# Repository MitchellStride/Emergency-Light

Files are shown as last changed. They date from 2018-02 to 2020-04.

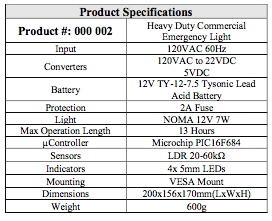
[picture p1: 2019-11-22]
pics/prod-spec.png

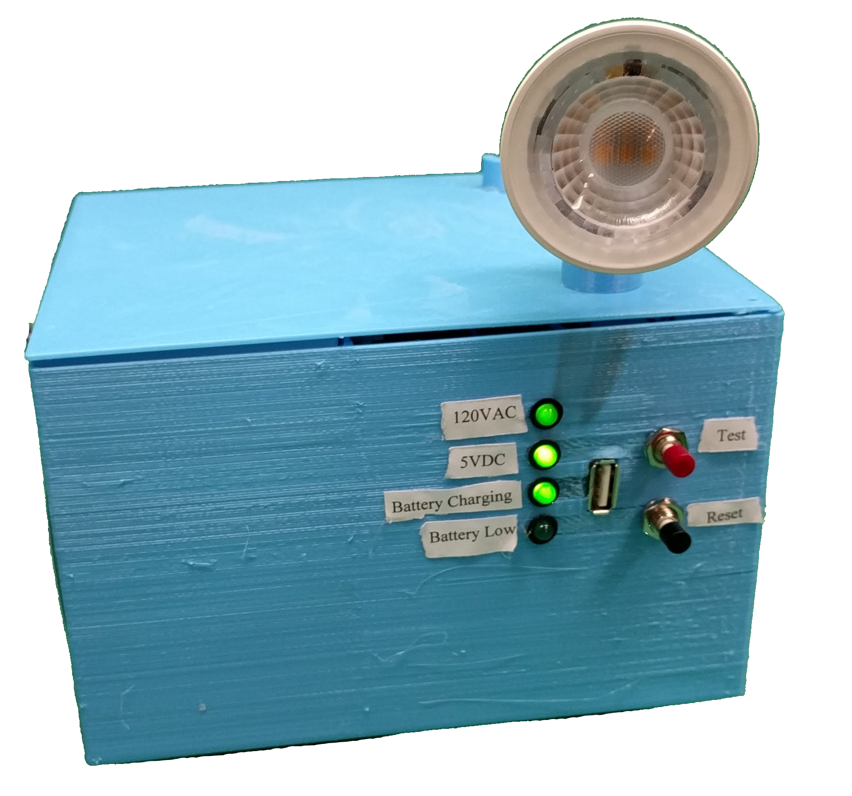
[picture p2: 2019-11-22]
pics/Emergency-Front.png

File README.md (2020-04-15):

# MayoStride Innovations

Emergency Light Lab by Mitchell Stride, and Jordan Mayo.

## Emergency Light Unit







## Product Specifications









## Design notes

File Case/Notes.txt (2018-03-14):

Case Notes
Inside
Battery,
Board mount
Transformer
Room for cables

Outside
Light Mount on top
Hole for Light mount wires
Hole for power plug cord
4 Leds
2 Switches buttons
usb charging slot
LDR hole

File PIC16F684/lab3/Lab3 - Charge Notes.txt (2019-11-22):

// From Lab3 Manuel
program LAB3_PWM_CHRG
dim dc1 as byte
main:
TRISA = S01
cmcon0=0 'comparatorsoff
ANSEL=$01
ADCON0=$80 'right justified
ADCON1=$70 'set clock frequency
TRISC = 0
PORTC=$FF 'initial value
PWM1_Init(1000) ' initializes PWM module, freq = 1kHz.
PWM1_Start ' starts PWM
While true
dc1= word(ADC_read(0) >> 2) 'read adc and kick two LSBs out Delay_ms(100) 'change duty every 100ms PWM1_Set_Duty(dc1) ' changes duty ratio
wend
end.

//Our Code
//tomoarr add comments, spruce up, see if works

program LAB3_PWM_CHRG
dim data1 as float
dim vadc as float
dim dc1 as float

main:
TRISA = $01
cmcon0=0 'comparatorsoff
ANSEL=$01
ADCON0=$80 'right justified
ADCON1=$70 'set clock frequency
TRISC = 0
PORTC=$FF 'initial value
PWM1_Init(1000) ' initializes PWM module, freq = 1kHz.
PWM1_Start ' starts PWM

While true
data1 = adc_read(0)
vadc = (5*data1)/1023
dc1 = 951.1-190.3*vadc
PWM1_Set_Duty(dc1)
Delay_ms(100)
wend
end

//Done
program LAB3_PWM_CHRG

dim vadc as float
dim dc1 as float
dim data1 as word

main:
TRISA = $01
cmcon0=0            'comparators off
ANSEL=$01
ADCON0=$80          'right justified
ADCON1=$70          'set clock frequency
TRISC = 0
PORTC=$FF           'initial value
PWM1_Init(1000)     'initializes PWM module, freq = 1kHz.
PWM1_Start          'starts PWM

While true
data1 = adc_read(0)         'Reading adc
vadc = (5*data1)/1023       'Converting
dc1 = 951.1-190.3*vadc      'Calculated conversion
PWM1_Set_Duty(dc1)          'Setting PWM
Delay_ms(100)
wend

end.

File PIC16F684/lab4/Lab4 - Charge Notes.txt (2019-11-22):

program Lab4_EmergencyLight

'Pinout of Circuit
'AI0 - Data for Vbattery (Pin13)
'AI1 - Rectified voltage read (Pin 12)
'AI2 - LDR read (Pin 11)

'RC0 - Test Button (Pin 10)
'RC1 - Charging LED (Pin 9)
'RC2 - Low Battery LED (Pin 10)
'RC3 - Light Relay (Pin 7)
'RC5 - PWM Charging (Pin5)

'Init Variables
dim pwm_data as float
dim pwm_vadc as float
dim pwm_dutyCycle as float
dim rectified_data as float
dim rectified_vadc as float
dim light_data as float
dim light_vadc as float

main:

'Init Ports (0-Output, 1-Input)
TRISA = %00000111   'RA7-RA0
TRISC = %00000001   'RC7-RC0
PORTA = %00000000   'RA7-RA0
PORTC = %00000000   'RC7-RC0

cmcon0 = 0    'Turn Comparators Off

'Init ADC
ANSEL = $0F
ADCON0 = $80
ADCON1 = $70

'PWM Init (lab3)
PWM1_Init(1000)
PWM1_Start

 PORTC.3 = 0' Turn Light Off

while true
    'Read battery level to set PWM
      pwm_data = adc_read(0)
      pwm_vadc = (5*pwm_data)/1023
      pwm_dutyCycle = 951.1-(190.3*pwm_vadc)
    'Read grid rectified voltage
      rectified_data = adc_read(1)
      rectified_vadc = (5*rectified_data)/1023
    'Read light value from LDR
      light_data = adc_read(2)
      light_vadc = (5*light_data)/1023

      if PORTC.0 = 1 then   'Read Switch, if not pushed
         if rectified_vadc > 3 then   'Rectified voltage available
            PWM1_Set_Duty(pwm_dutyCycle)    'Set duty cycle
            PORTC.2 = 0                     'Low Battery LED OFF
            PORTC.1 = 1                     'Battery Charging LED ON
            PORTC.3 = 0                     'Light OFF

         else                          'Rectified voltage not available
            if pwm_vadc > 3.83 then         'Battery is operational
               if light_vadc > 2.5 then     'Dark Room
                  PORTC.1 = 0               'Battery Charging LED OFF
                  PORTC.3 = 1               'Light ON
               else                         'Light Room
                  PORTC.1 = 0               'Battery Charging LED OFF
                  PORTC.3 = 0               'Light OFF
               end if
            else                            'Battery is NOT operational
               PORTC.2 = 1                  'Low Battery LED ON
               PORTC.1 = 0                  'Battery Charging LED ON
               PORTC.3 = 0                  'Light OFF
            end if
         end if

      else                            'If Switch is pushed
          PORTC.3 = 0                 'Light ON
          PORTC.1 = 1                 'Battery Charging LED OFF
      end if

      delay_ms(1000)                  'Delay a second
  wend
end.

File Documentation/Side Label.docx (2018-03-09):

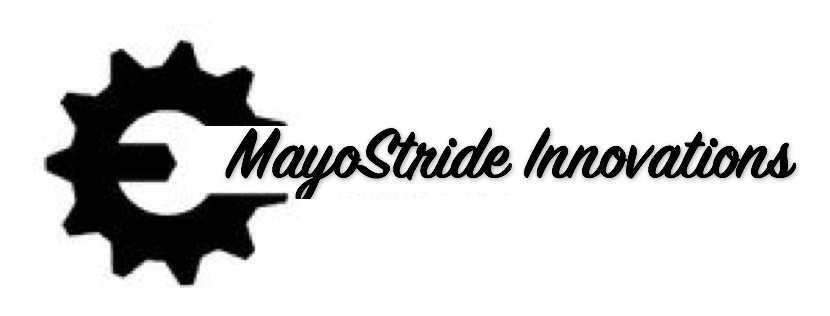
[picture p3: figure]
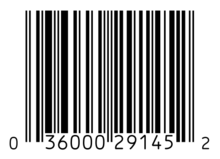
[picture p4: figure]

MayoStride Innovations

S.J Carew – EN1040

230 Elizabeth Ave, St. Johns

NL A1C 5S7

Canada

Product Specifications
Product #: 000 002 | Heavy Duty Commercial Emergency Light
Input | 120VAC 60Hz
Converters | 120VAC to 22VDC 5VDC
Battery | 12V TY-12-7.5 Tysonic Lead Acid Battery
Protection | 2A Fuse
Light | NOMA 12V 7W
Max Operation Length | 13 Hours
µController | Microchip PIC16F684
Sensors | LDR 20-60kΩ
Indicators | 4x 5mm LEDs
Mounting | VESA Mount
Dimensions | 200x156x170mm(LxWxH)
Weight | 600g

Reset

Test

120VAC

5VDC

Battery Low

Battery Charging

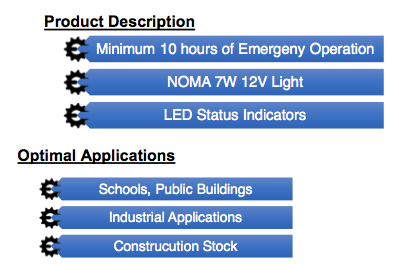
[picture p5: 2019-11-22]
pics/brochure-snip.png

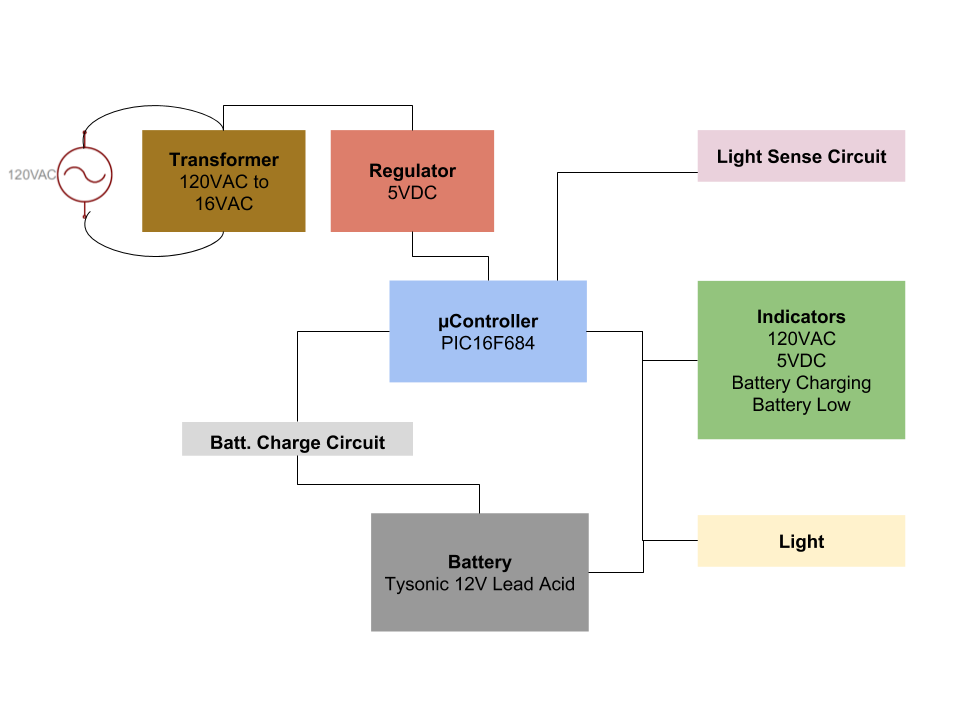
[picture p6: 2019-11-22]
pics/Block-Diagram.png

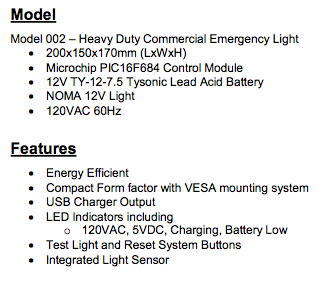
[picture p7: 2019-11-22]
pics/txtpic.png

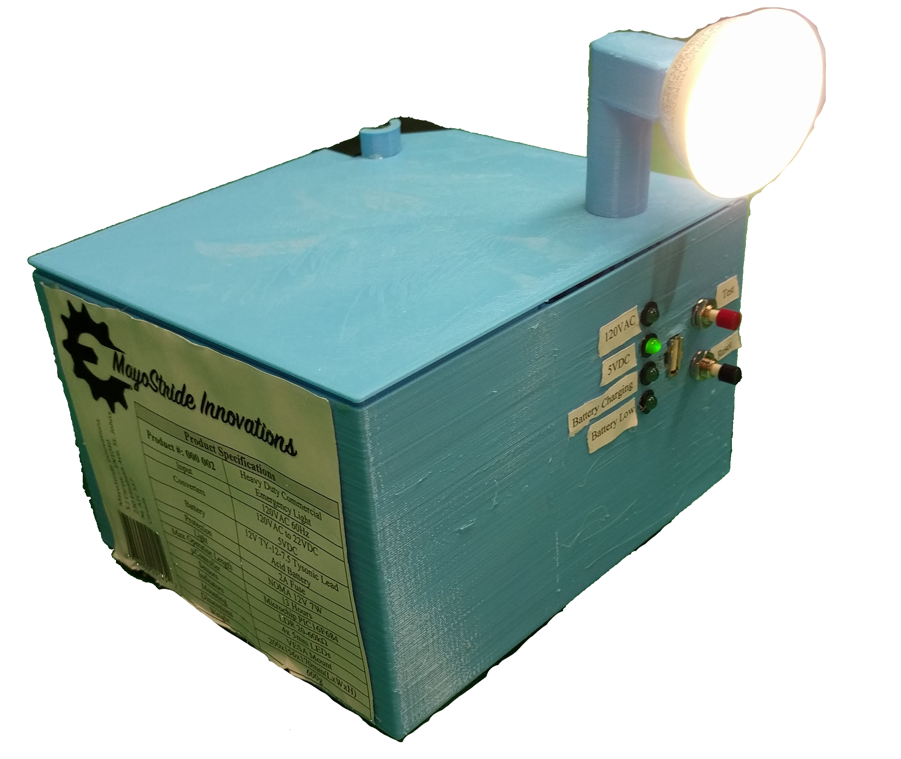
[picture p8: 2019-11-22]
pics/TriMetric-View Emergency-Light.png

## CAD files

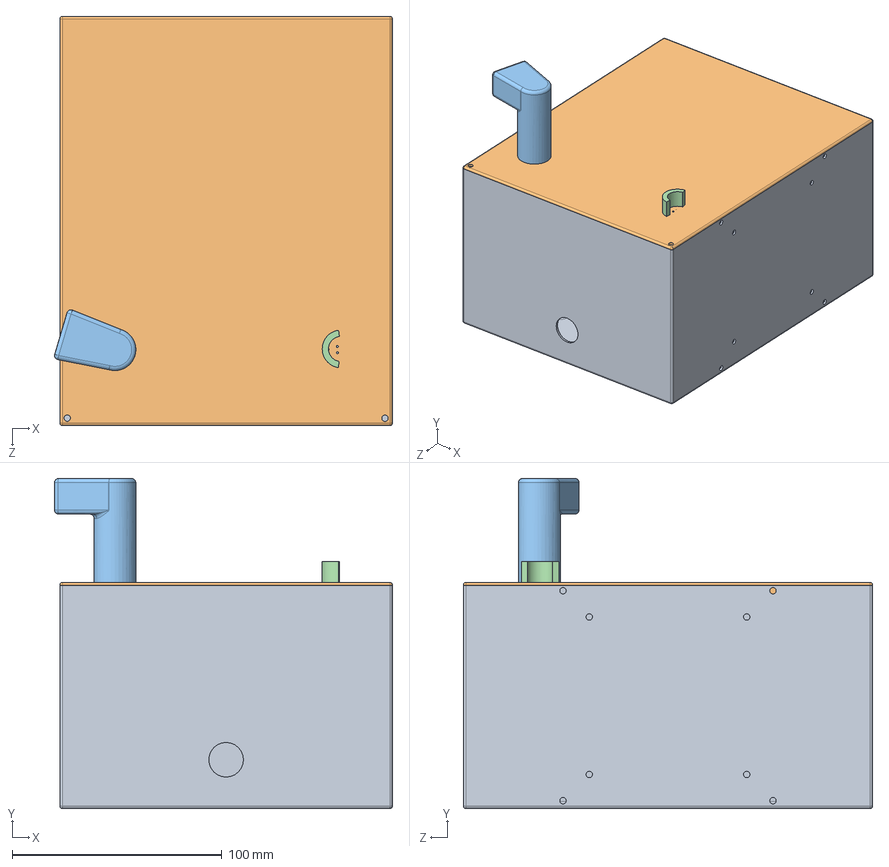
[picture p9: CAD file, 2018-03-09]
Case/Assembly.SLDASM
161.0 x 157.2 x 195.0 mm
CaseBase
CaseCover
Light Mount
Shroud

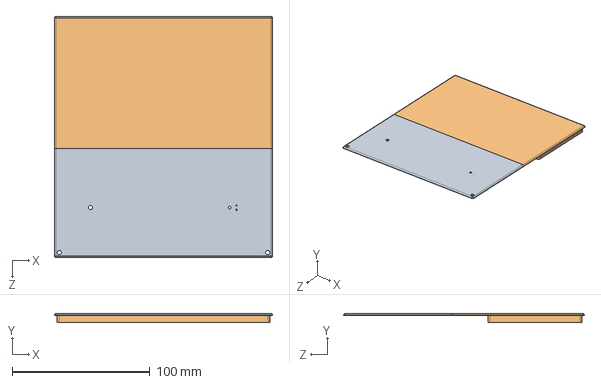
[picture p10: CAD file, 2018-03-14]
Case/Case Cover Fix/Case Top Fix Assem.SLDASM
158.5 x 6.50 x 175.0 mm
CaseCover1
CaseCover2

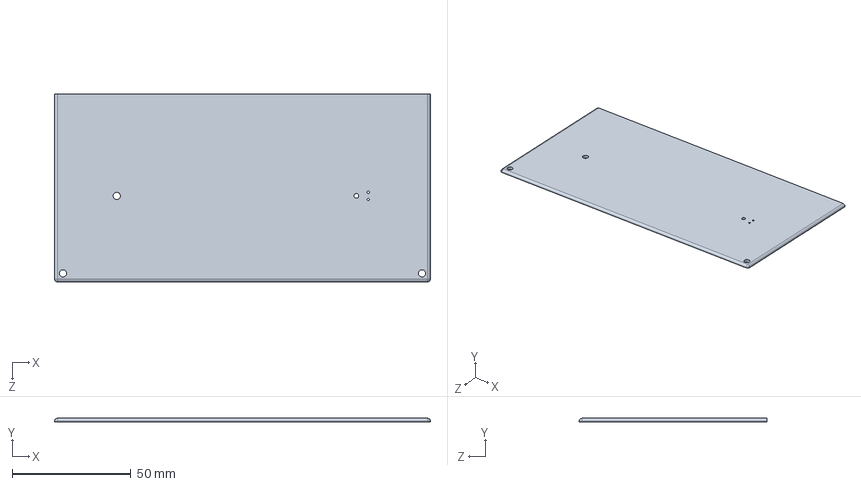
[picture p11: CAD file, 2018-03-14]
Case/Case Cover Fix/CaseCover1.SLDPRT
158.5 x 1.50 x 79.1 mm

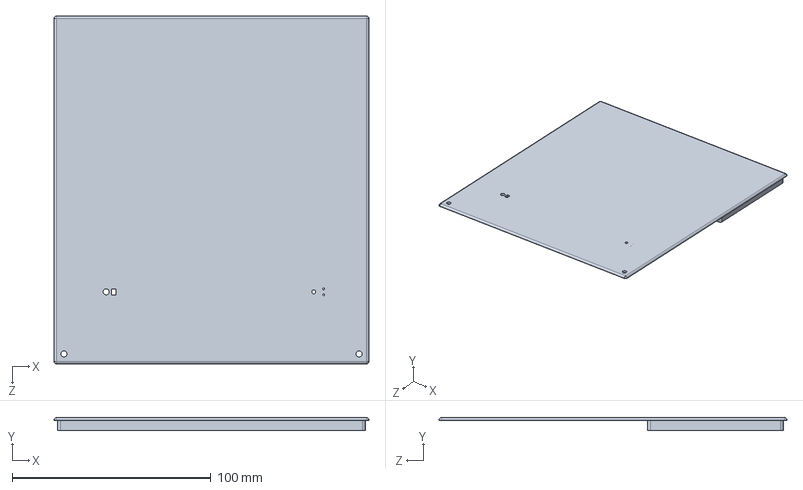
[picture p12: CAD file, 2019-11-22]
Case/Case Cover Fix/FINAL/CaseCover FINAL FIX.SLDPRT
158.5 x 6.50 x 175.0 mm

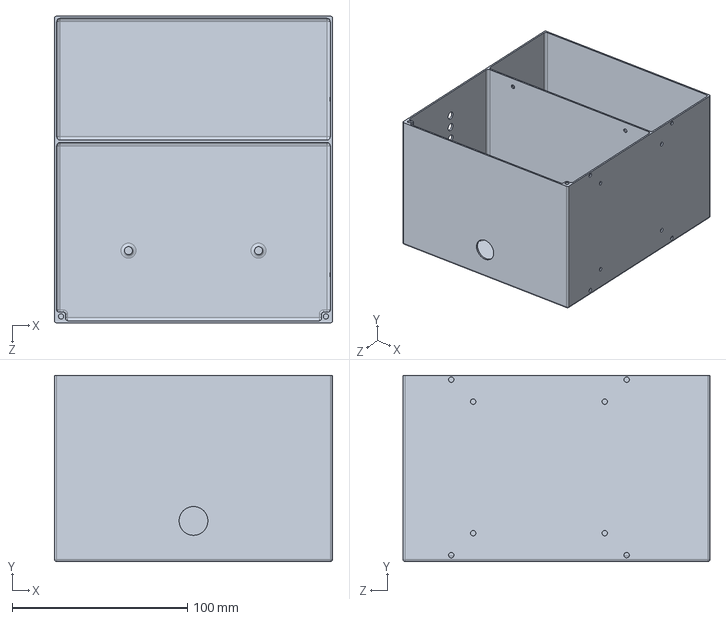
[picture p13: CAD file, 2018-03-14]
Case/CaseBase.SLDPRT
158.5 x 106.2 x 175.0 mm

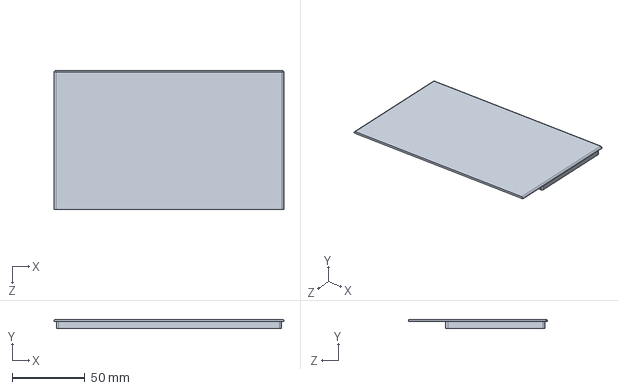
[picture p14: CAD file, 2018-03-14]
Case/Case Cover Fix/CaseCover2.SLDPRT
158.5 x 6.50 x 95.9 mm

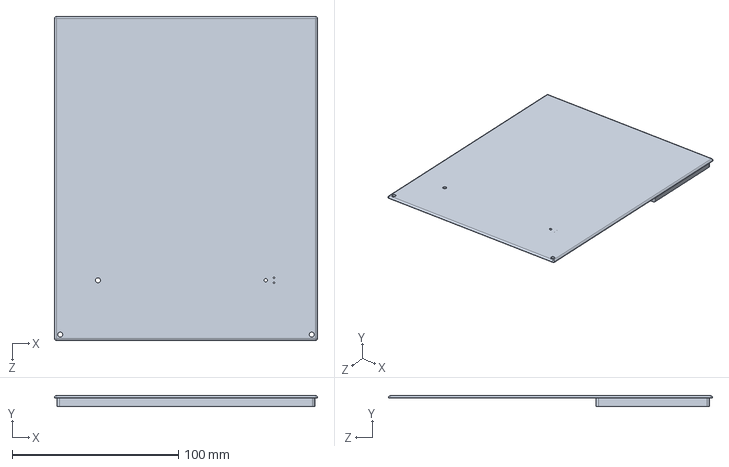
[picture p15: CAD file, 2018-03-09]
Case/CaseCover.SLDPRT
158.5 x 6.50 x 195.0 mm

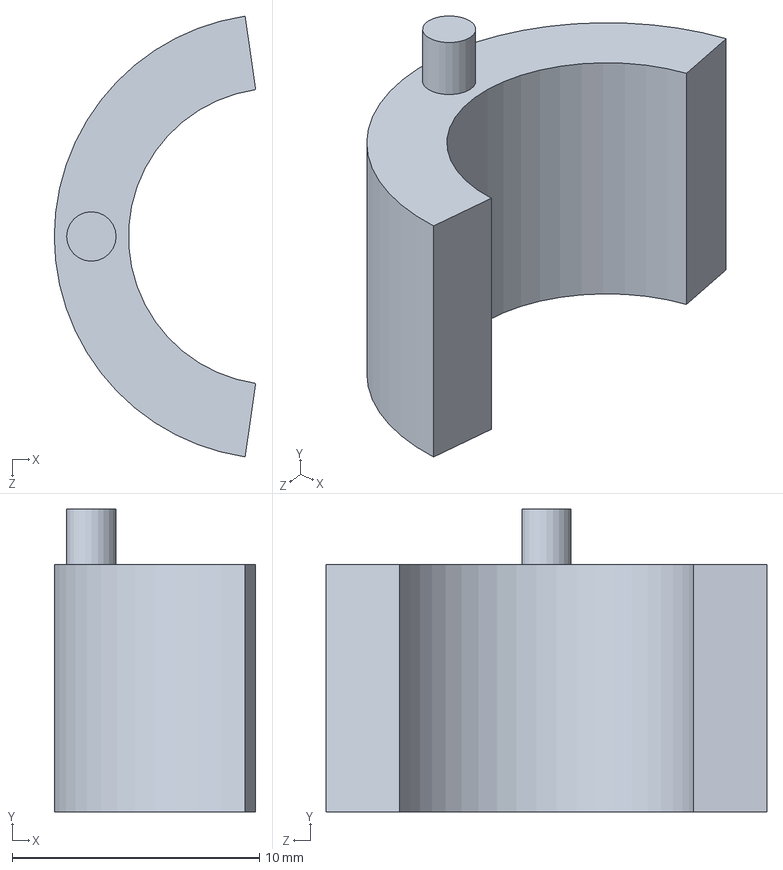
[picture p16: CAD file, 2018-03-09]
Case/Shroud.SLDPRT
8.14 x 12.2 x 17.8 mm

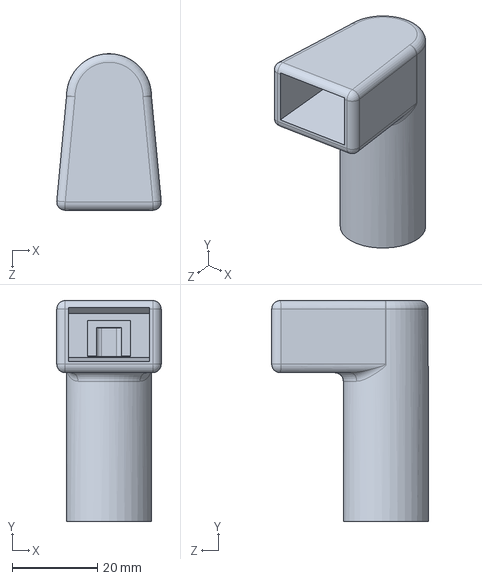
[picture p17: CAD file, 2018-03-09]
Case/Light Mount.SLDPRT
24.6 x 52.0 x 36.9 mm

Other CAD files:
Case/STLs/Case Top Fix Assem - CaseCover1-1.STL
Case/STLs/Case Top Fix Assem - CaseCover2-1.STL
Case/Case Cover Fix/FINAL/CaseCover FINAL FIX.STL
Case/STLs/CaseBase.STL
Case/STLs/CaseCover.STL
Case/STLs/Light Mount.STL
Case/STLs/Shroud.STL

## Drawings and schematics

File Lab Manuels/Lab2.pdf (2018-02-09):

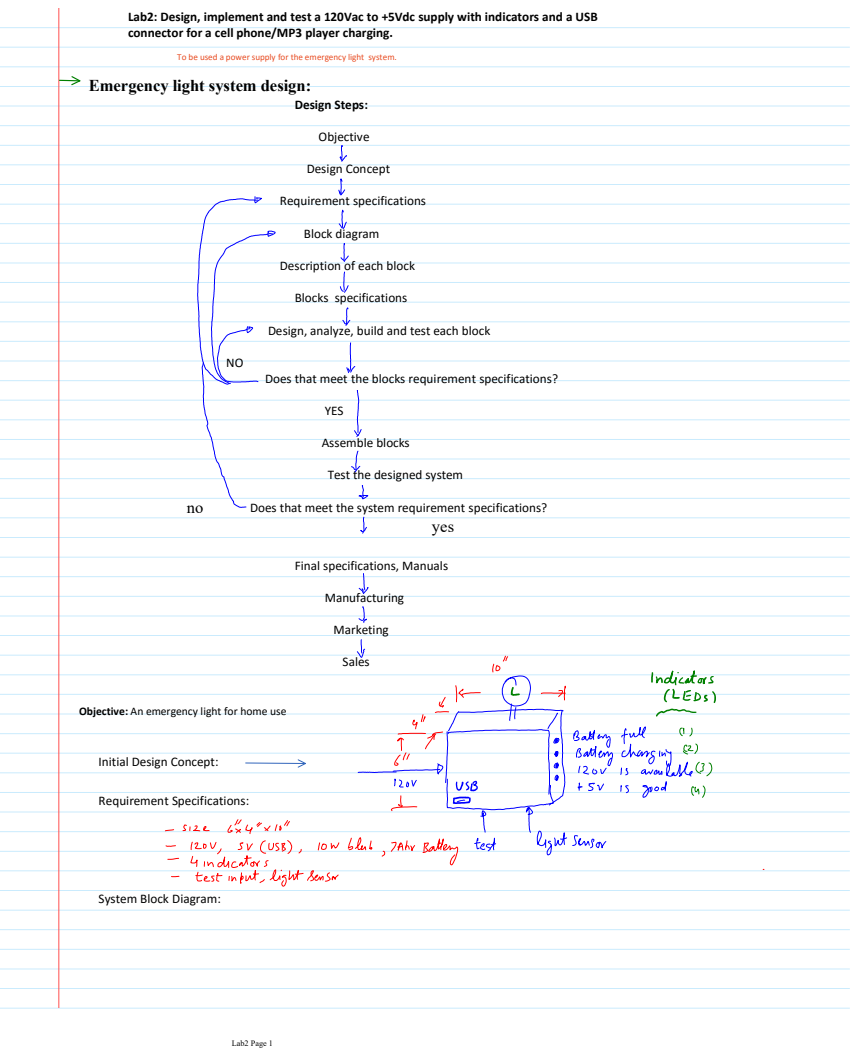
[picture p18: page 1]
yes; Lab2 Page 1

Lab2: Design, implement and test a 120Vac to +5Vdc supply with indicators and a USB
connector for a cell phone/MP3 player charging.
To be used a power supply for the emergency light system.
Emergency light system design:

Design Steps:
Objective
Design Concept
Requirement specifications
Block diagram
Description of each block
Blocks specifications
Design, analyze, build and test each block
Does that meet the blocks requirement specifications?
YES
Assemble blocks
Test the designed system
Does that meet the system requirement specifications?
Final specifications, Manuals
Manufacturing
Marketing
Sales

Objective: An emergency light for home use
Initial Design Concept:
Requirement Specifications:

System Block Diagram:

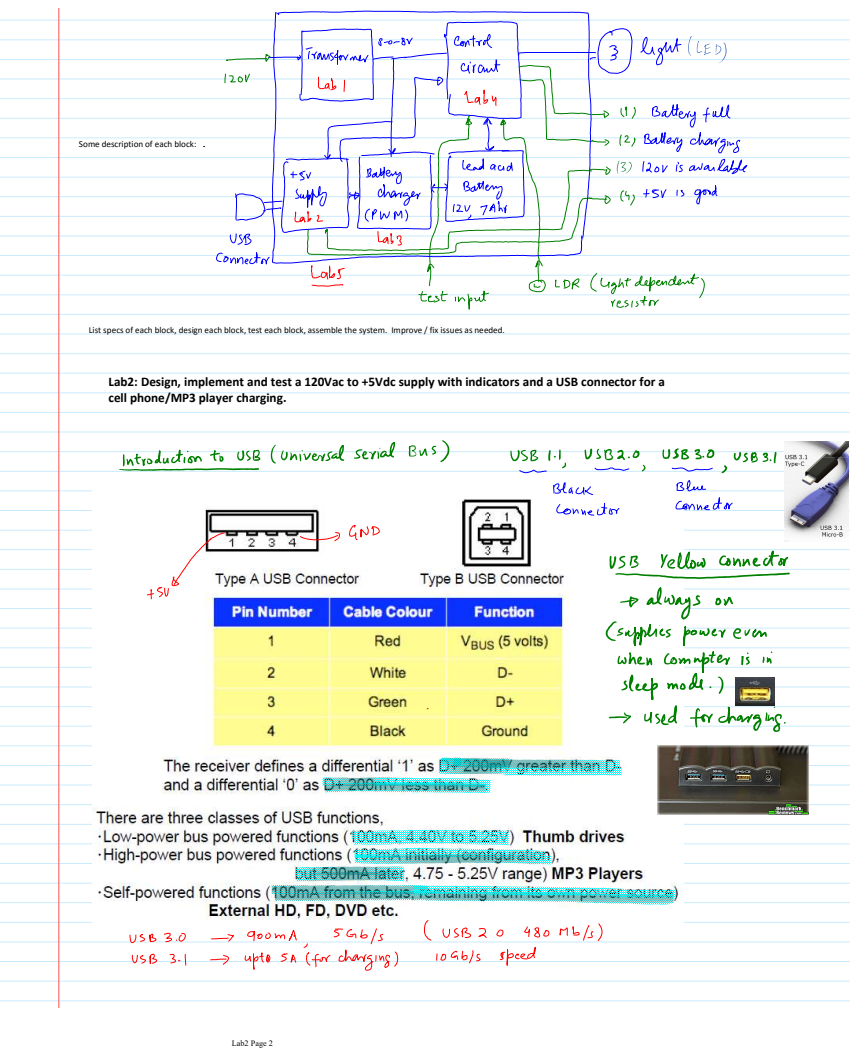
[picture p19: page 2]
Lab2 Page 2

Some description of each block:

List specs of each block, design each block, test each block, assemble the system. Improve / fix issues as needed.
Lab2: Design, implement and test a 120Vac to +5Vdc supply with indicators and a USB connector for a
cell phone/MP3 player charging.

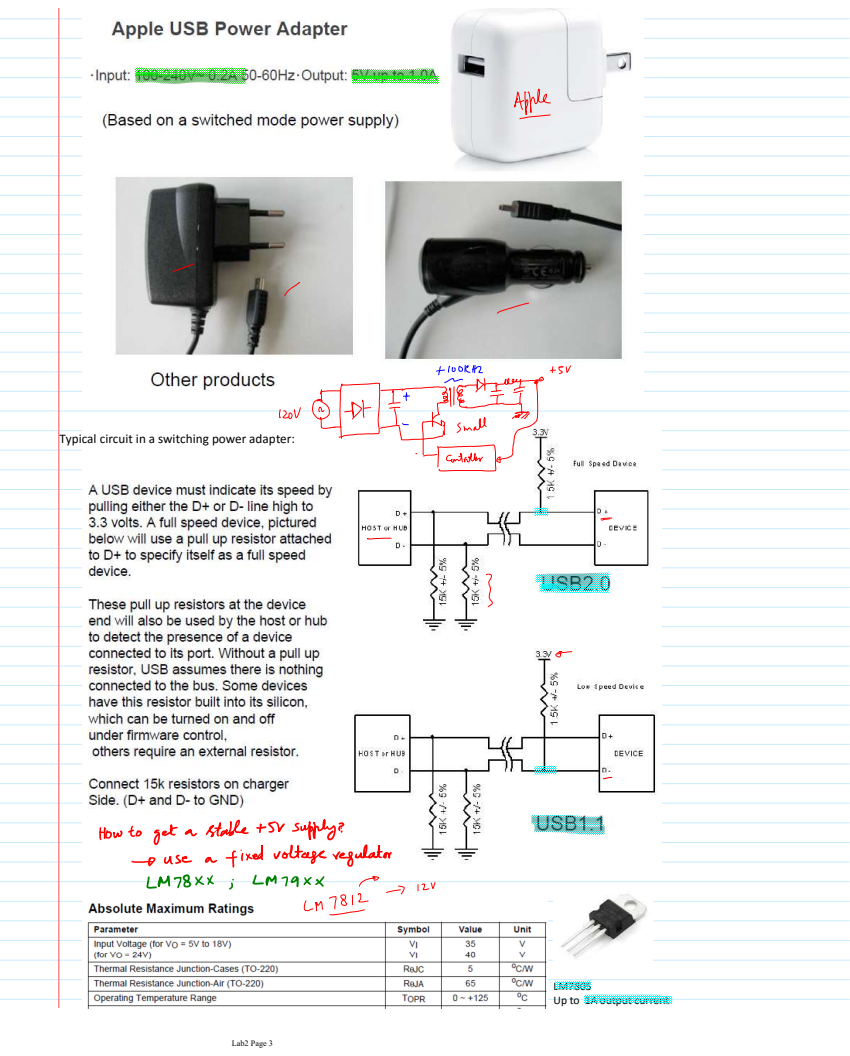
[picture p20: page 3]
Lab2 Page 3

Typical circuit in a switching power adapter:

Up to 1A output current

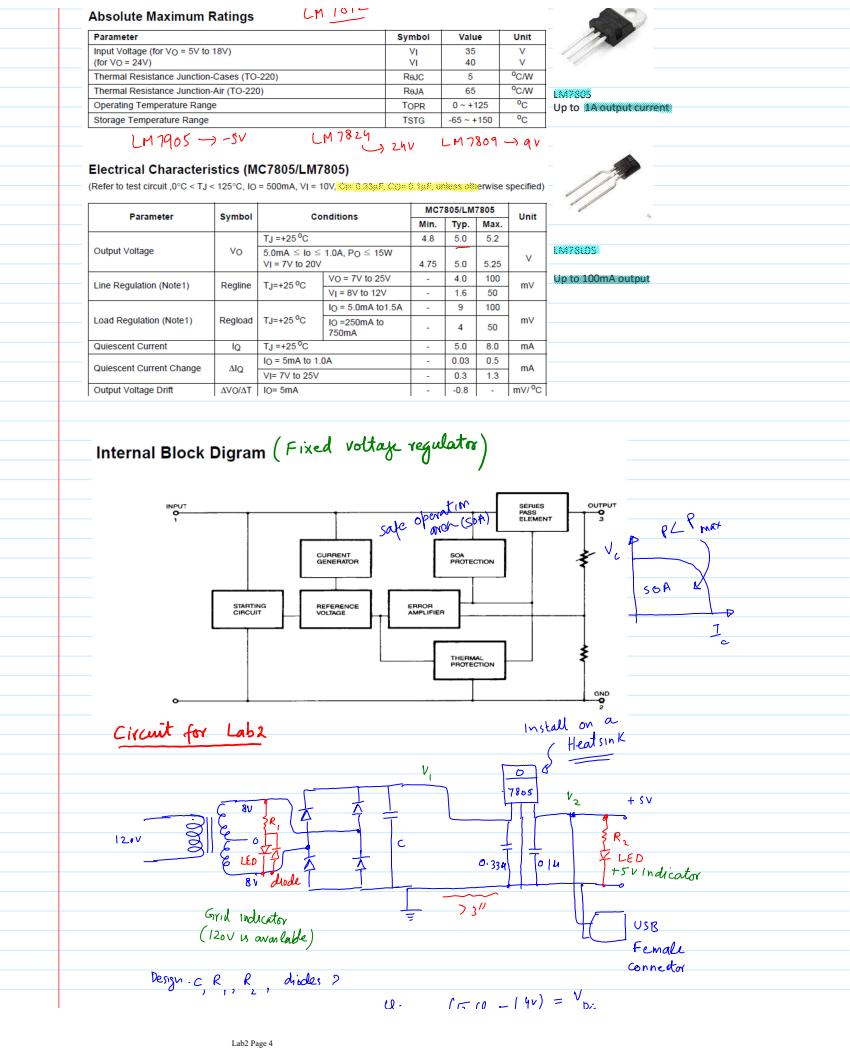
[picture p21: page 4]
Lab2 Page 4

Up to 1A output current

Up to 100mA output

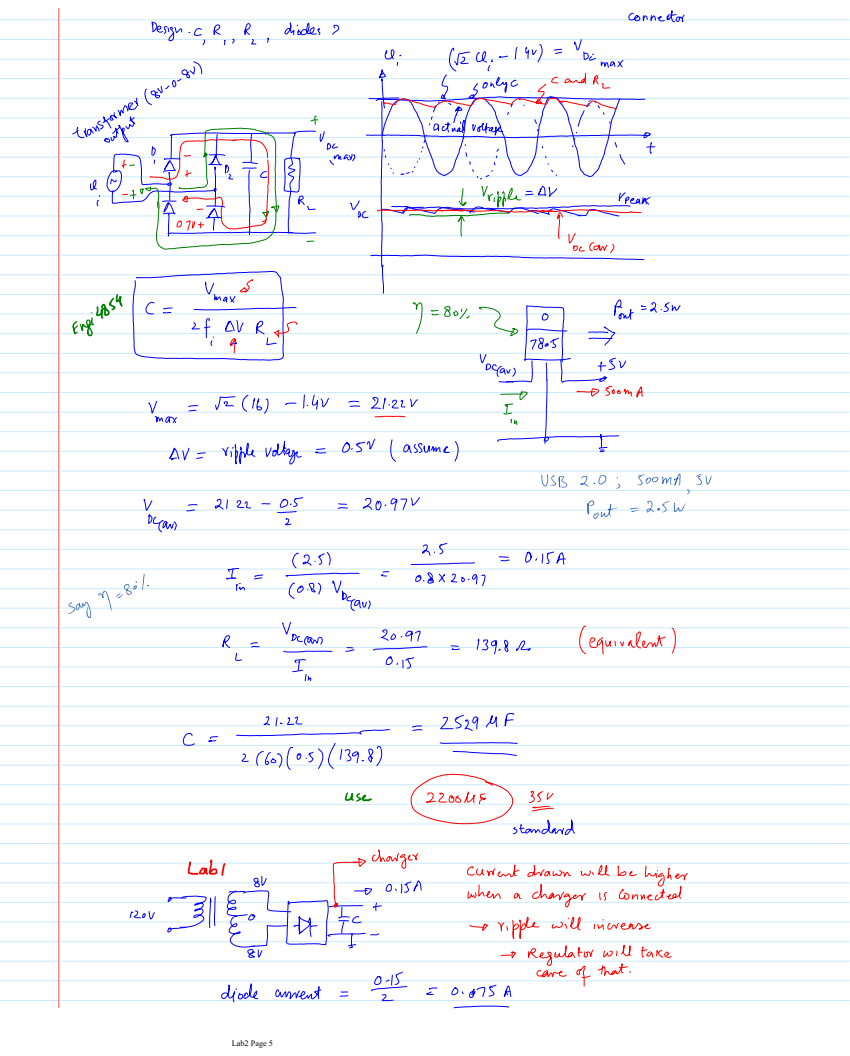
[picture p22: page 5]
Lab2 Page 5

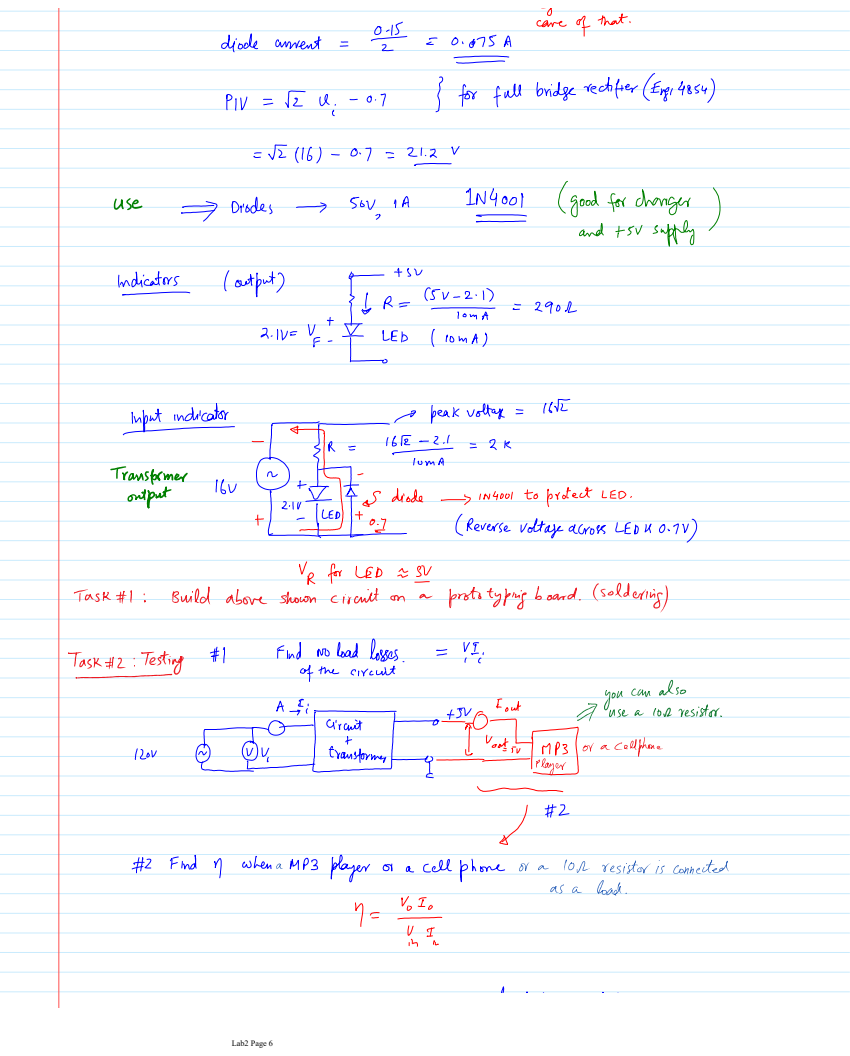
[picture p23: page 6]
Lab2 Page 6

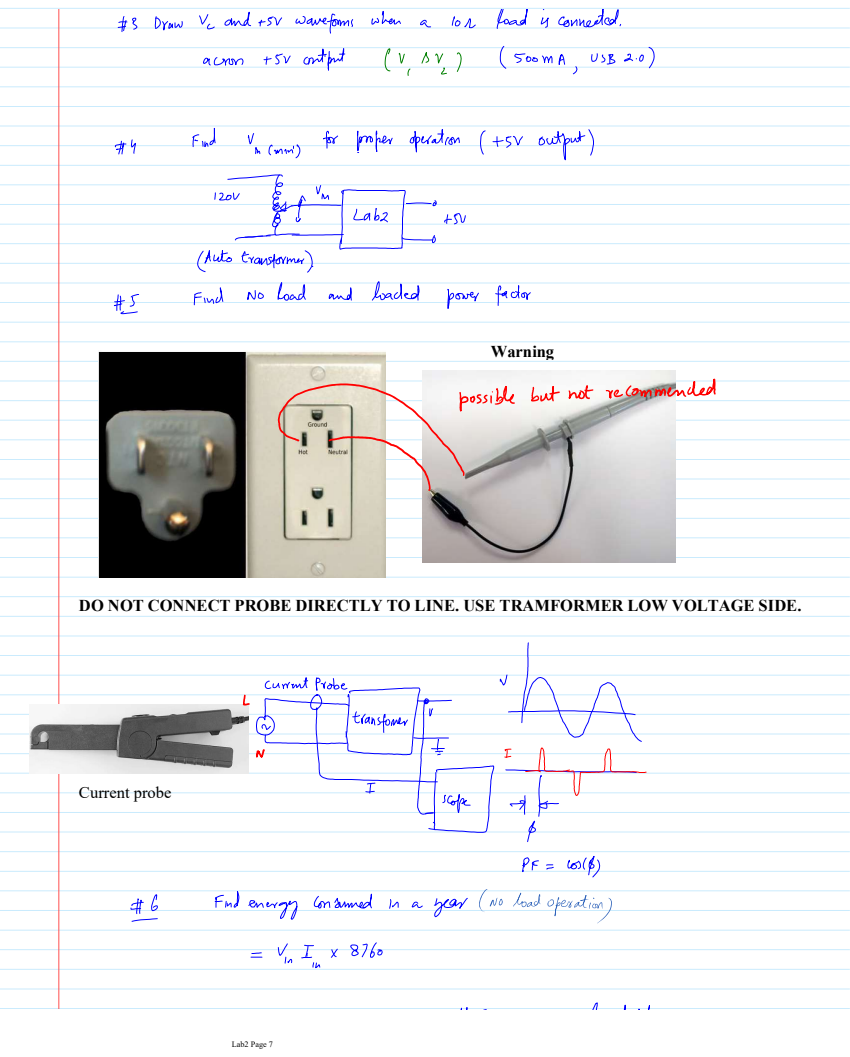
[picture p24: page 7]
Current probe; Warning; Lab2 Page 7

DO NOT CONNECT PROBE DIRECTLY TO LINE. USE TRAMFORMER LOW VOLTAGE SIDE.

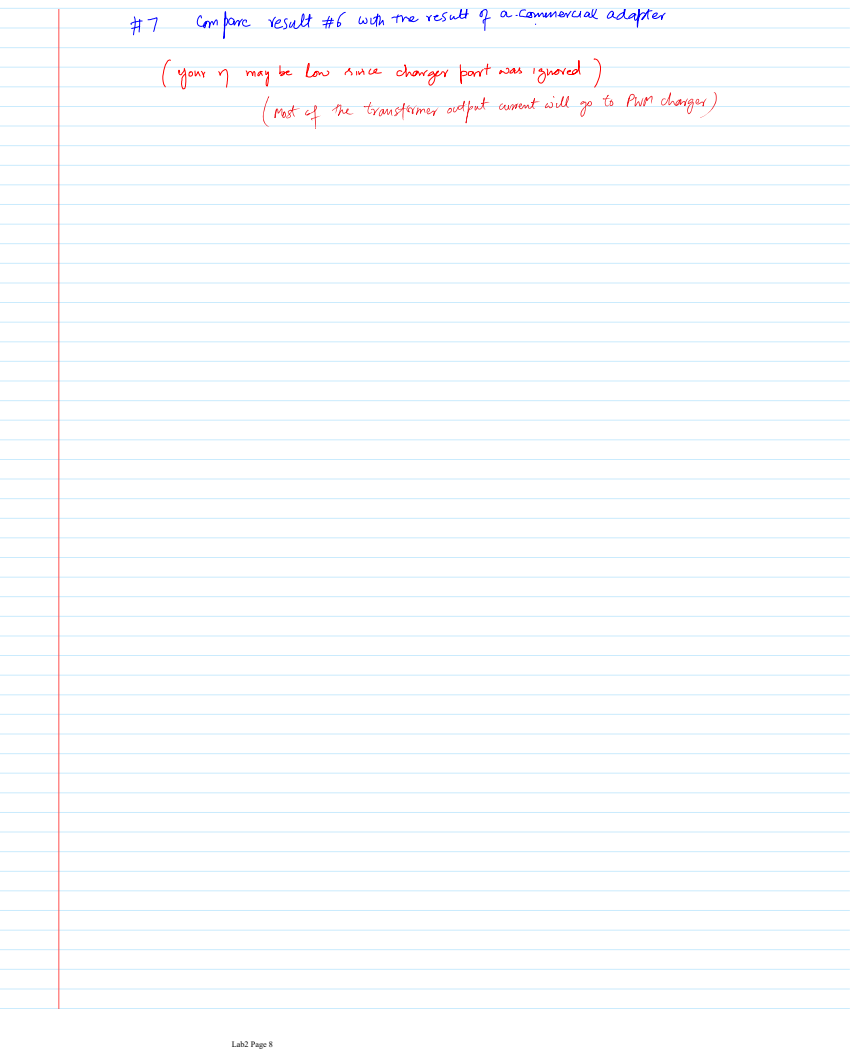
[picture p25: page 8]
Lab2 Page 8

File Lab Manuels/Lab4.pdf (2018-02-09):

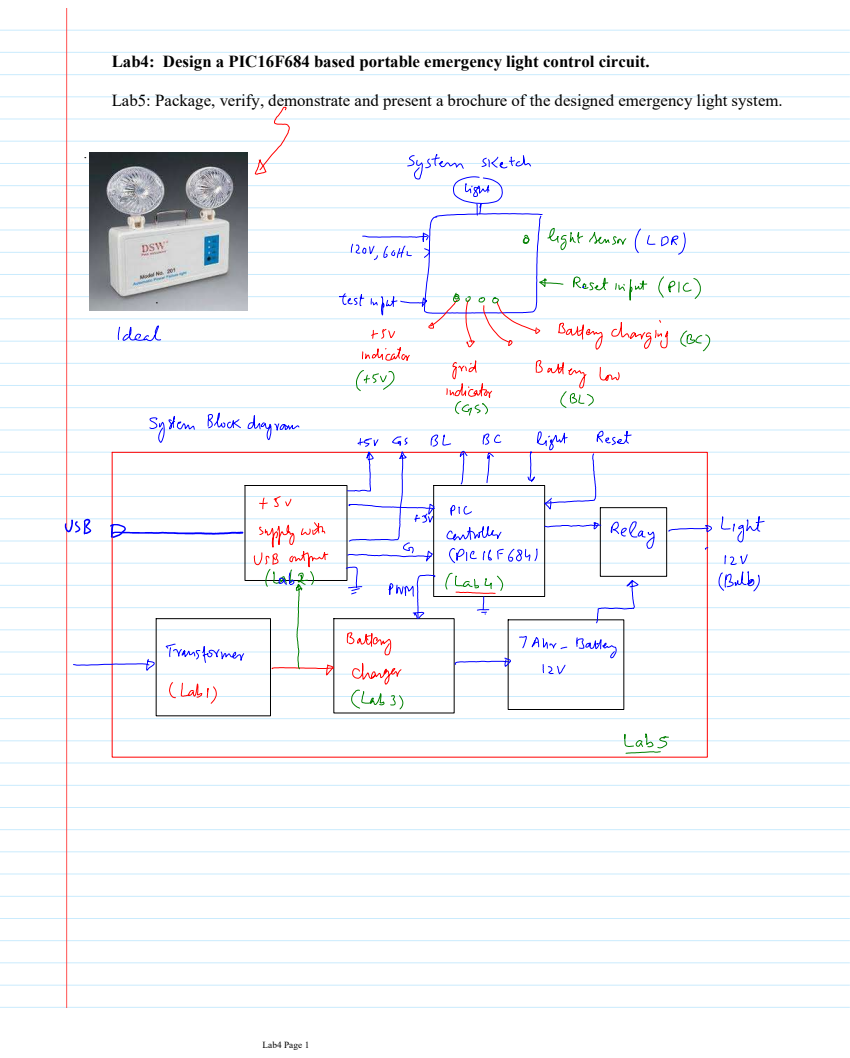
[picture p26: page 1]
Lab4 Page 1

Lab4: Design a PIC16F684 based portable emergency light control circuit.

Lab5: Package, verify, demonstrate and present a brochure of the designed emergency light system.

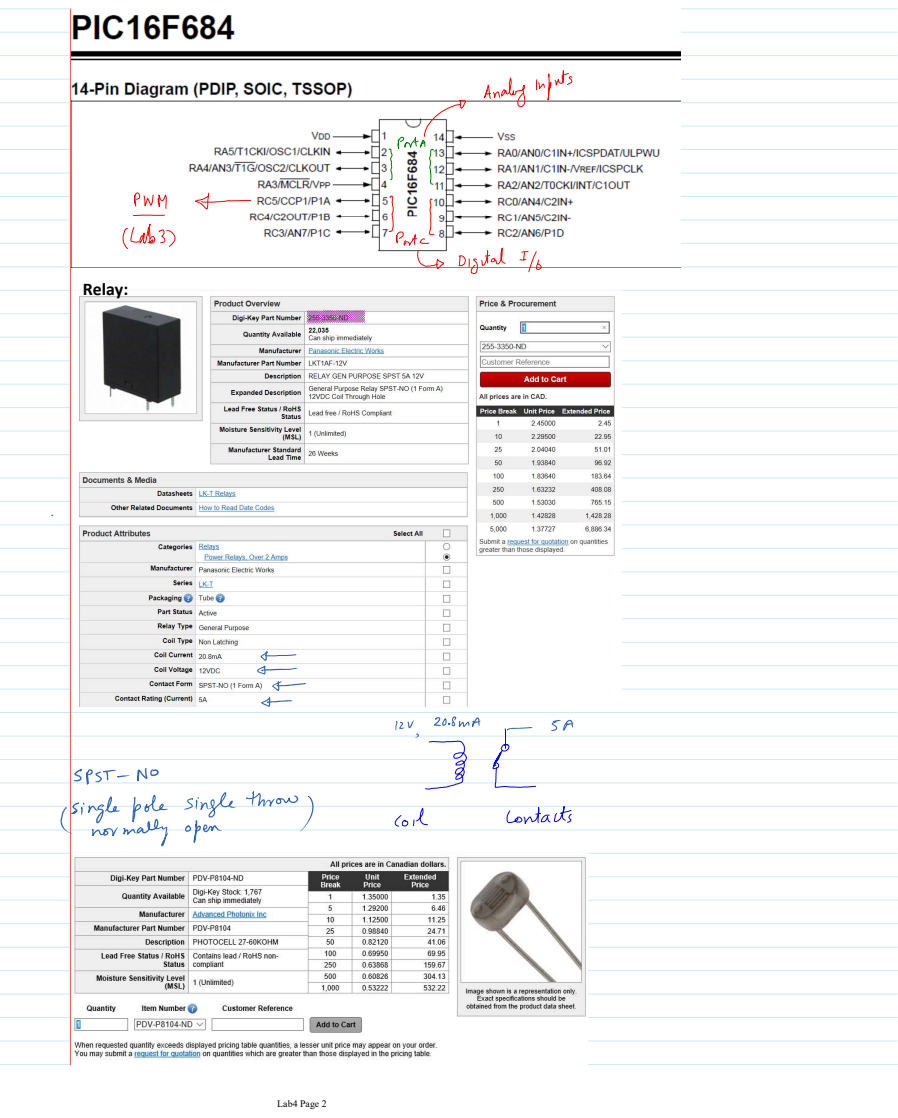
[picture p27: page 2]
Relay:; Lab4 Page 2

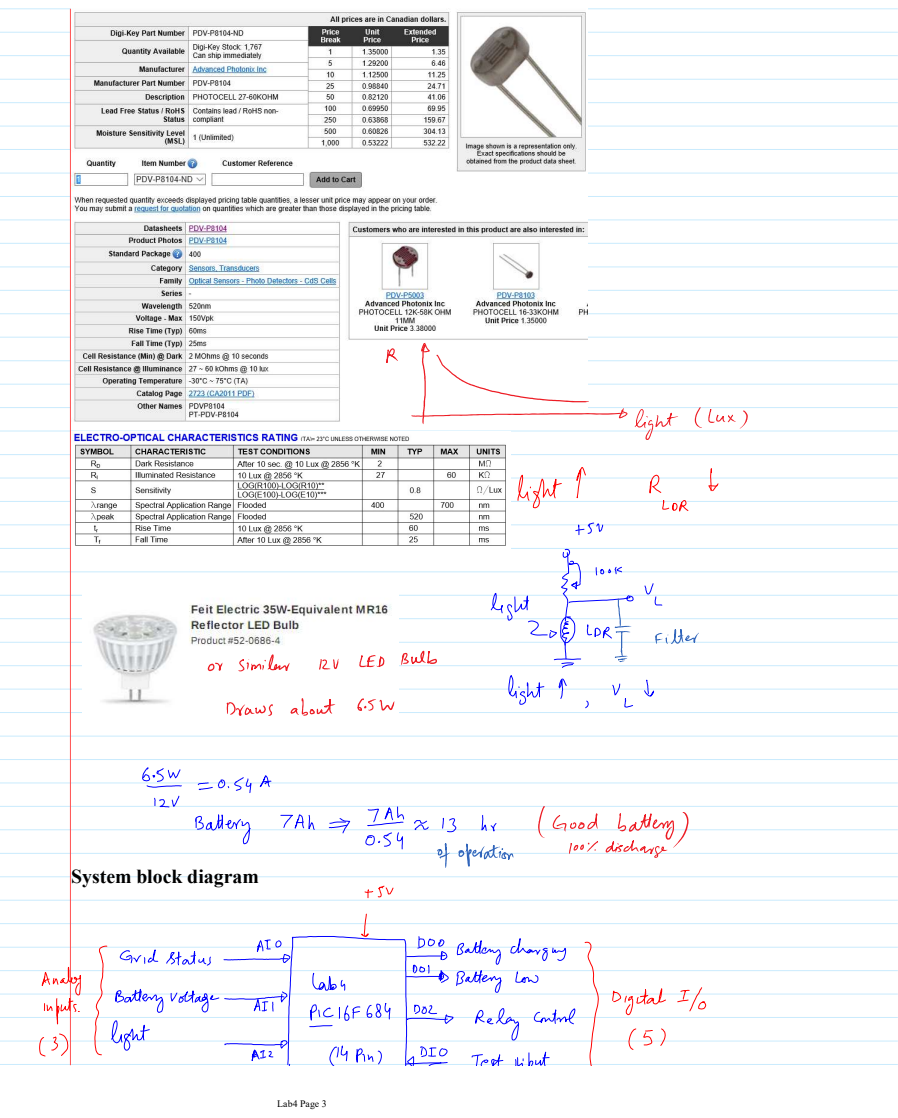
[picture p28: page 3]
Lab4 Page 3

System block diagram

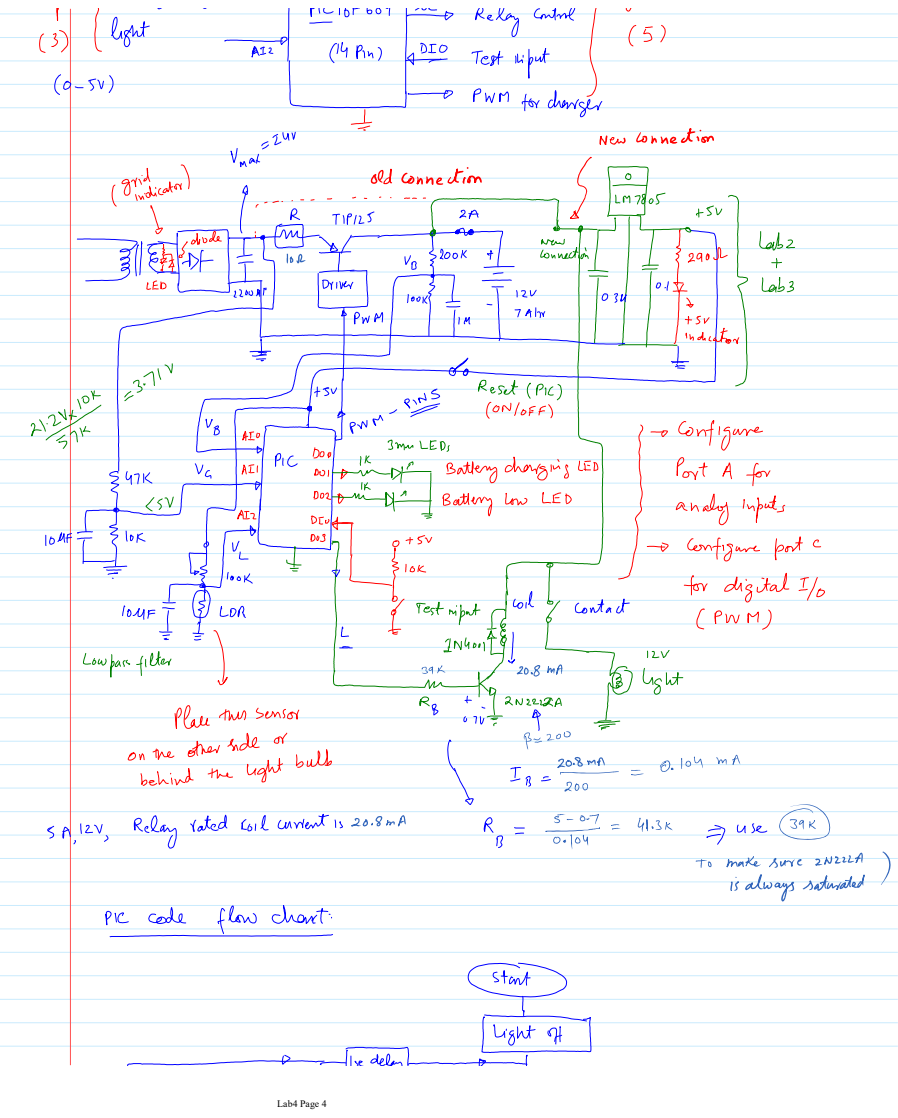
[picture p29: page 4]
Lab4 Page 4

Lab4 Page 5

Lab4 Page 6

Depending upon your code, your test results table may be different from the above table.

Some good circuit building examples using prototype boards

Watch: https://youtu.be/mIE79Vai5z0

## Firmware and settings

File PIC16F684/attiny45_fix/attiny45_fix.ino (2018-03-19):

/*****************************
 * Program for an ATTiny45
 * Fix lab4 by turning on relay when button is pushed
 *****************************/

#define testSwitch 1
#define Relay 2

void setup() {
  pinMode(testSwitch, INPUT);
  pinMode(Relay, OUTPUT);
  delay(100);
}

void loop() {
  if(digitalRead(testSwitch) == LOW)
    digitalWrite(Relay, HIGH);
  
  
  if(digitalRead(testSwitch) == HIGH)
    digitalWrite(Relay, LOW);
  
}

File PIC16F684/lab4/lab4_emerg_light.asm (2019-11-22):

_main:

;lab4_emerg_light.mbas,25 :: 		main:
;lab4_emerg_light.mbas,28 :: 		TRISA = $1F   'RA7-RA0
	MOVLW      31
	MOVWF      TRISA+0
;lab4_emerg_light.mbas,29 :: 		TRISC = $01   'RC7-RC0
	MOVLW      1
	MOVWF      TRISC+0
;lab4_emerg_light.mbas,30 :: 		PORTA = $00   'RA7-RA0
	CLRF       PORTA+0
;lab4_emerg_light.mbas,31 :: 		PORTC = $00   'RC7-RC0
	CLRF       PORTC+0
;lab4_emerg_light.mbas,33 :: 		cmcon0 = 0    'Turn Comparators Off
	CLRF       CMCON0+0
;lab4_emerg_light.mbas,36 :: 		ANSEL = $0F
	MOVLW      15
	MOVWF      ANSEL+0
;lab4_emerg_light.mbas,37 :: 		ADCON0 = $80
	MOVLW      128
	MOVWF      ADCON0+0
;lab4_emerg_light.mbas,38 :: 		ADCON1 = $70
	MOVLW      112
	MOVWF      ADCON1+0
;lab4_emerg_light.mbas,41 :: 		PWM1_Init(1000)
	BCF        T2CON+0, 0
	BCF        T2CON+0, 1
	BSF        T2CON+0, 0
	BCF        T2CON+0, 1
	MOVLW      249
	MOVWF      PR2+0
	CALL       _PWM1_Init+0
;lab4_emerg_light.mbas,42 :: 		PWM1_Start
	CALL       _PWM1_Start+0
;lab4_emerg_light.mbas,44 :: 		while true
L__main2:
;lab4_emerg_light.mbas,45 :: 		while PORTA.4
L__main7:
	BTFSC      PORTA+0, 4
	GOTO       L__main7
;lab4_emerg_light.mbas,49 :: 		if (PORTA.3) then            'Read Switch, if not pushed
	BTFSS      PORTA+0, 3
	GOTO       L__main12
;lab4_emerg_light.mbas,50 :: 		PORTC.3 = 1                 'Light ON
	BSF        PORTC+0, 3
;lab4_emerg_light.mbas,51 :: 		PORTC.4 = 1                 'Battery Charging LED OFF
	BSF        PORTC+0, 4
	GOTO       L__main13
;lab4_emerg_light.mbas,53 :: 		else
L__main12:
;lab4_emerg_light.mbas,56 :: 		pwm_data = adc_read(0)
	CLRF       FARG_ADC_Read_channel+0
	CALL       _ADC_Read+0
	CALL       _Word2Double+0
	MOVF       R0+0, 0
	MOVWF      _pwm_data+0
	MOVF       R0+1, 0
	MOVWF      _pwm_data+1
	MOVF       R0+2, 0
	MOVWF      _pwm_data+2
	MOVF       R0+3, 0
	MOVWF      _pwm_data+3
;lab4_emerg_light.mbas,57 :: 		pwm_vadc = (5*pwm_data)/1023
	MOVLW      0
	MOVWF      R4+0
	MOVLW      0
	MOVWF      R4+1
	MOVLW      32
	MOVWF      R4+2
	MOVLW      129
	MOVWF      R4+3
	CALL       _Mul_32x32_FP+0
	MOVLW      0
	MOVWF      R4+0
	MOVLW      192
	MOVWF      R4+1
	MOVLW      127
	MOVWF      R4+2
	MOVLW      136
	MOVWF      R4+3
	CALL       _Div_32x32_FP+0
	MOVF       R0+0, 0
	MOVWF      _pwm_vadc+0
	MOVF       R0+1, 0
	MOVWF      _pwm_vadc+1
	MOVF       R0+2, 0
	MOVWF      _pwm_vadc+2
	MOVF       R0+3, 0
	MOVWF      _pwm_vadc+3
;lab4_emerg_light.mbas,58 :: 		pwm_dutyCycle = 951.1-(190.3*pwm_vadc)
	MOVLW      205
	MOVWF      R4+0
	MOVLW      76
	MOVWF      R4+1
	MOVLW      62
	MOVWF      R4+2
	MOVLW      134
	MOVWF      R4+3
	CALL       _Mul_32x32_FP+0
	MOVF       R0+0, 0
	MOVWF      R4+0
	MOVF       R0+1, 0
	MOVWF      R4+1
	MOVF       R0+2, 0
	MOVWF      R4+2
	MOVF       R0+3, 0
	MOVWF      R4+3
	MOVLW      102
	MOVWF      R0+0
	MOVLW      198
	MOVWF      R0+1
	MOVLW      109
	MOVWF      R0+2
	MOVLW      136
	MOVWF      R0+3
	CALL       _Sub_32x32_FP+0
	MOVF       R0+0, 0
	MOVWF      _pwm_dutyCycle+0
	MOVF       R0+1, 0
	MOVWF      _pwm_dutyCycle+1
	MOVF       R0+2, 0
	MOVWF      _pwm_dutyCycle+2
	MOVF       R0+3, 0
	MOVWF      _pwm_dutyCycle+3
;lab4_emerg_light.mbas,60 :: 		rectified_data = adc_read(1)
	MOVLW      1
	MOVWF      FARG_ADC_Read_channel+0
	CALL       _ADC_Read+0
	CALL       _Word2Double+0
	MOVF       R0+0, 0
	MOVWF      _rectified_data+0
	MOVF       R0+1, 0
	MOVWF      _rectified_data+1
	MOVF       R0+2, 0
	MOVWF      _rectified_data+2
	MOVF       R0+3, 0
	MOVWF      _rectified_data+3
;lab4_emerg_light.mbas,61 :: 		rectified_vadc = (5*rectified_data)/1023
	MOVLW      0
	MOVWF      R4+0
	MOVLW      0
	MOVWF      R4+1
	MOVLW      32
	MOVWF      R4+2
	MOVLW      129
	MOVWF      R4+3
	CALL       _Mul_32x32_FP+0
	MOVLW      0
	MOVWF      R4+0
	MOVLW      192
	MOVWF      R4+1
	MOVLW      127
	MOVWF      R4+2
	MOVLW      136
	MOVWF      R4+3
	CALL       _Div_32x32_FP+0
	MOVF       R0+0, 0
	MOVWF      _rectified_vadc+0
	MOVF       R0+1, 0
	MOVWF      _rectified_vadc+1
	MOVF       R0+2, 0
	MOVWF      _rectified_vadc+2
	MOVF       R0+3, 0
	MOVWF      _rectified_vadc+3
;lab4_emerg_light.mbas,63 :: 		light_data = adc_read(2)
	MOVLW      2
	MOVWF      FARG_ADC_Read_channel+0
	CALL       _ADC_Read+0
	CALL       _Word2Double+0
	MOVF       R0+0, 0
	MOVWF      _light_data+0
	MOVF       R0+1, 0
	MOVWF      _light_data+1
	MOVF       R0+2, 0
	MOVWF      _light_data+2
	MOVF       R0+3, 0
	MOVWF      _light_data+3
;lab4_emerg_light.mbas,64 :: 		light_vadc = (5*light_data)/1023
	MOVLW      0
	MOVWF      R4+0
	MOVLW      0
	MOVWF      R4+1
	MOVLW      32
	MOVWF      R4+2
	MOVLW      129
	MOVWF      R4+3
	CALL       _Mul_32x32_FP+0
	MOVLW      0
	MOVWF      R4+0
	MOVLW      192
	MOVWF      R4+1
	MOVLW      127
	MOVWF      R4+2
	MOVLW      136
	MOVWF      R4+3
	CALL       _Div_32x32_FP+0
	MOVF       R0+0, 0
	MOVWF      _light_vadc+0
	MOVF       R0+1, 0
	MOVWF      _light_vadc+1
	MOVF       R0+2, 0
	MOVWF      _light_vadc+2
	MOVF       R0+3, 0
	MOVWF      _light_vadc+3
;lab4_emerg_light.mbas,66 :: 		if rectified_vadc > 2.5 then   'Rectified voltage available
	MOVF       _rectified_vadc+0, 0
	MOVWF      R4+0
	MOVF       _rectified_vadc+1, 0
	MOVWF      R4+1
	MOVF       _rectified_vadc+2, 0
	MOVWF      R4+2
	MOVF       _rectified_vadc+3, 0
	MOVWF      R4+3
	MOVLW      0
	MOVWF      R0+0
	MOVLW      0
	MOVWF      R0+1
	MOVLW      32
	MOVWF      R0+2
	MOVLW      128
	MOVWF      R0+3
	CALL       _Compare_Double+0
	MOVLW      255
	BTFSC      STATUS+0, 0
	MOVLW      0
	MOVWF      R0+0
	MOVF       R0+0, 0
	BTFSC      STATUS+0, 2
	GOTO       L__main15
;lab4_emerg_light.mbas,67 :: 		PWM1_Set_Duty(pwm_dutyCycle)    'Set duty cycle
	MOVF       _pwm_dutyCycle+0, 0
	MOVWF      R0+0
	MOVF       _pwm_dutyCycle+1, 0
	MOVWF      R0+1
	MOVF       _pwm_dutyCycle+2, 0
	MOVWF      R0+2
	MOVF       _pwm_dutyCycle+3, 0
	MOVWF      R0+3
	CALL       _Double2Byte+0
	MOVF       R0+0, 0
	MOVWF      FARG_PWM1_Set_Duty_new_duty+0
	CALL       _PWM1_Set_Duty+0
;lab4_emerg_light.mbas,68 :: 		PORTC.2 = 0                     'Low Battery LED OFF
	BCF        PORTC+0, 2
;lab4_emerg_light.mbas,69 :: 		PORTC.4 = 1                     'Battery Charging LED ON
	BSF        PORTC+0, 4
;lab4_emerg_light.mbas,70 :: 		PORTC.3 = 0                     'Light OFF
	BCF        PORTC+0, 3
	GOTO       L__main16
;lab4_emerg_light.mbas,72 :: 		else                          'Rectified voltage not available
L__main15:
;lab4_emerg_light.mbas,73 :: 		PORTC.4 = 0                 'Battery Charging LED OFF
	BCF        PORTC+0, 4
;lab4_emerg_light.mbas,74 :: 		if pwm_vadc > 3.83 then         'Battery is operational
	MOVF       _pwm_vadc+0, 0
	MOVWF      R4+0
	MOVF       _pwm_vadc+1, 0
	MOVWF      R4+1
	MOVF       _pwm_vadc+2, 0
	MOVWF      R4+2
	MOVF       _pwm_vadc+3, 0
	MOVWF      R4+3
	MOVLW      184
	MOVWF      R0+0
	MOVLW      30
	MOVWF      R0+1
	MOVLW      117
	MOVWF      R0+2
	MOVLW      128
	MOVWF      R0+3
	CALL       _Compare_Double+0
	MOVLW      255
	BTFSC      STATUS+0, 0
	MOVLW      0
	MOVWF      R0+0
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

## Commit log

2018-02-16 Added charge code
    [Lab3.cfg]
2018-03-09 added lab4 code v1
    [lab4_emerg_light.cfg]
2018-03-09 added intial SW case model
    [CaseBase.SLDPRT]
2018-03-09 model started
    [CaseBase.SLDPRT]
2018-03-09 completed case?
    [CaseBase.SLDPRT, CaseBase.STL, CaseCover.SLDPRT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]
2018-03-09 added assembly and render
    [Assembly.SLDASM, CaseCover.SLDPRT, CaseCover.STL]
2018-03-14 shortened up case top
    [Assembly.SLDASM, Case Top Fix Assem - CaseCover1-1.STL, Case Top Fix Assem - CaseCover2-1.STL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]
2018-03-19 added pic code
    [LED Test Project.cfg, Lab3.cfg]
2019-11-22 alienware push
    [CaseCover FINAL FIX.SLDPRT, CaseCover FINAL FIX.STL]
